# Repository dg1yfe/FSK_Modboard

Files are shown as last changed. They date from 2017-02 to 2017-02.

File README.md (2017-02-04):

# FSK_Modboard
A little amplifier board for Demodulator &amp; Modulator access in Motorola MC micro transceivers 

The board provides uses a dual OP-Amp to do the following:

1) Transmit Path
   - Provide an external input for direct (wide-band) modulator access
   - Amplify the signal supplied via the external input by a factor of 2.7
   - Add microphone audio signal and (amplified) external signal and route the mix to the modulator
     (be sure to disconnect or mute your microphone when using the external input)
 
2) Receive Path
   - Pick-up the demodulated signal right after the demodulator and amplify it by 10
   - Provide the amplified signal (amplitude about ~500 mV) at an external output

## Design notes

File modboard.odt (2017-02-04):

R1 - 47

R2 - 22k

R3 - 220k

R4 - 22k

R5 - 220k

R6 - 220k

R7 - 82k

C1 - 47n

C2 – 4u7

C3 - 4u7

C4 - 100p

C5 - 4u7

C6 - 47n

X1 - RX Signal vom Demodulator (z.B. Demod-IC / Pin 5)

X2 - FSK RX Signal zum Modem, DSUB Pin 7 (z.B. D652 Kathode)

X2A – mit Koppelkondensator

X2B – ohne Koppelkondensator

X3 - FSK TX Signal vom Modem, DSUB Pin 9 (z.B. D651 Kathode)

X4 - NF Signal vom Mikrofon (z.B. U601 / Pin 4)

X5 - Kombiniertes TX Signal zum Modulator (L602)

X6 - 9,6 V (z.B. U801 / Pin 11)

X7 - 4,8 V (z.B. U601 / Pin 9 )

X8 - GND / Masse (z.B. U601 / Pin 7)

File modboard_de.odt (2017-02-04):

R1 – 47 Ohm

R2 – 22 kOhm

R3 – 220 kOhm

R4 – 22 kOhm

R5 – 220 kOhm

R6 – 220 kOhm

R7 – 82 kOhm

C1 – 47 nF

C2 – 4,7 µF

C3 – 4,7 µF

C4 – 100 pF

C5 – 4,7 µF

C6 – 47nF

Kontakt Beschreibung Anschlusspunkt

X1 RX Signal vom Demodulator (Demod-IC / Pin 5)

X2 FSK RX Signal zum Modem, DSUB Pin 7 (z.B. D652 Kathode)

X2A – mit Koppelkondensator

X2B – ohne Koppelkondensator

X3 Kombiniertes TX Signal zum Modulator (L602)

X4 NF Signal vom Mikrofon (z.B. U601 / Pin 4)

X5 FSK TX Signal vom Modem, DSUB Pin 9 (z.B. D651 Kathode)

X6 9,6 V (z.B. U801 / Pin 11)

X7 4,8 V (z.B. U601 / Pin 9 )

X8 GND / Masse (z.B. U601 / Pin 7)

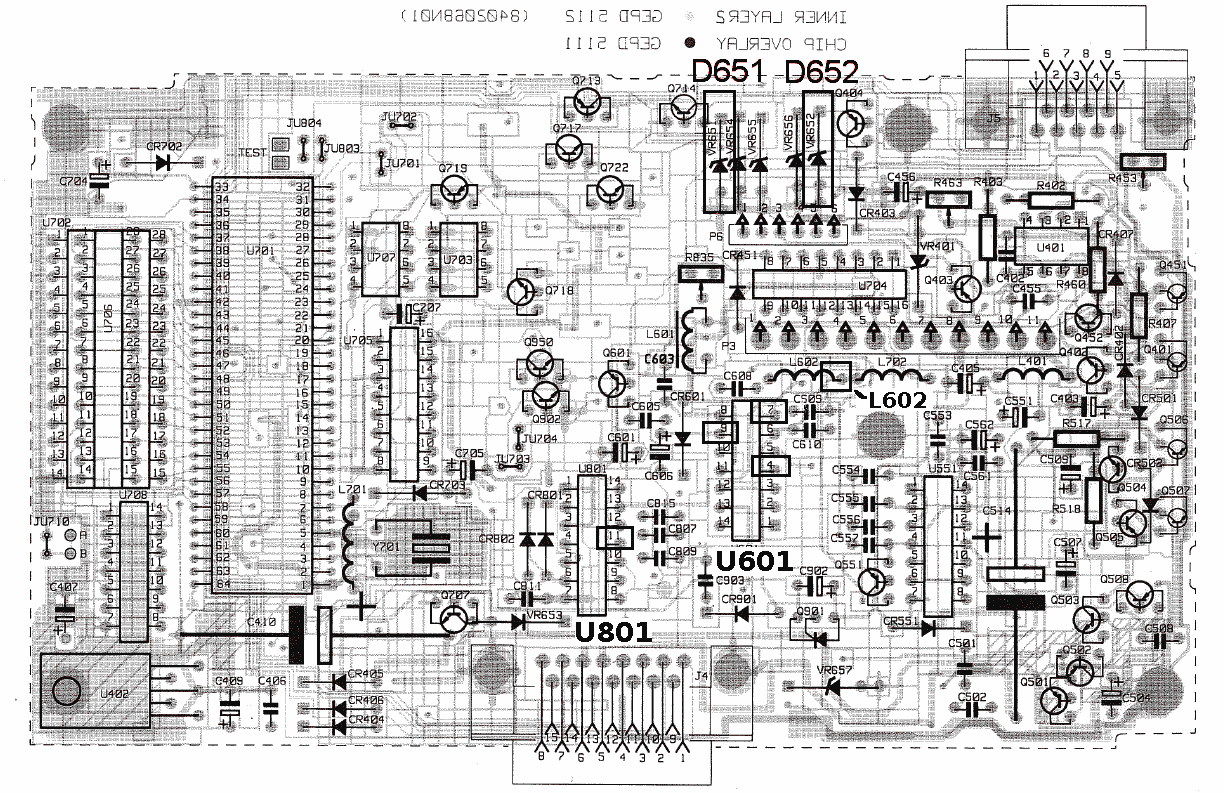
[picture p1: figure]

Command Board

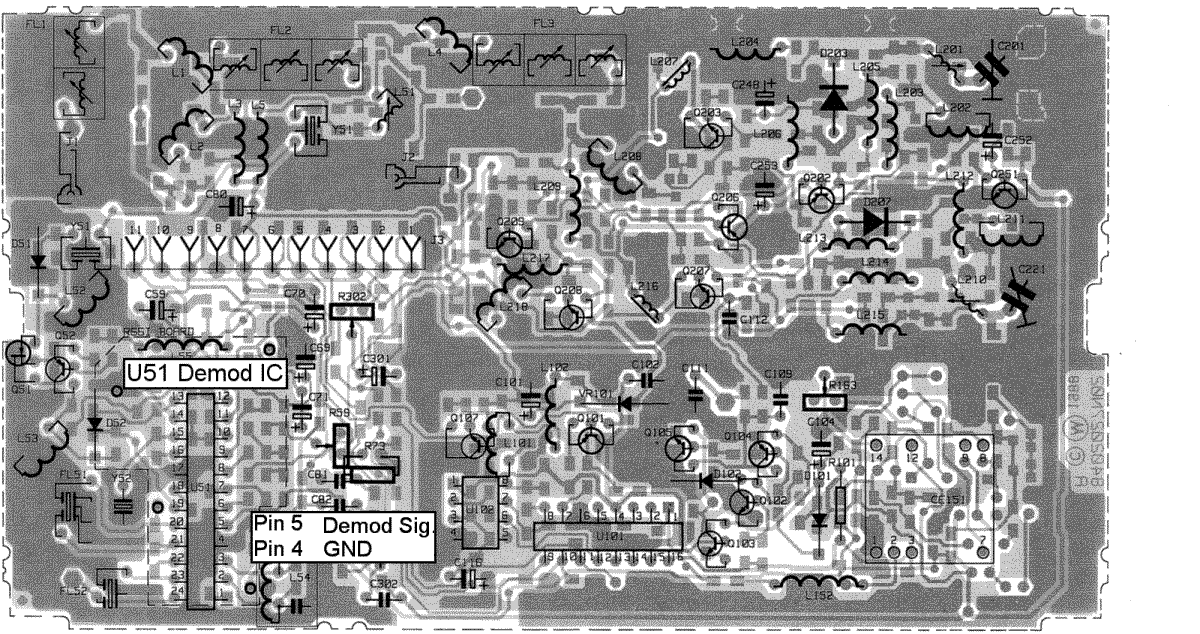
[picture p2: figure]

RF Board

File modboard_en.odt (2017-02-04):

R1 – 47 Ohm

R2 – 22 k

R3 – 220 k

R4 – 22 k

R5 – 220 k

R6 – 220 k

R7 – 82 k

C1 – 47 n

C2 – 4u7

C3 – 4u7

C4 – 100 p

C5 – 4u7

C6 – 47 n

Soldering Point Description Connection in TRX

X1 RX signal from discriminator Demod-IC / Pin 5

X2 FSK RX out to Modem, DSUB Pin 7 e.g. D652 cathode

X2A – AC-coupled

X2B – DC-coupled

X3 Combined signal / to modulator L602

X4 NF audio from microphone U601 / Pin 4

X5 FSK TX sig. from Modem, DSUB Pin 9 e.g. D651 cathode

X6 9.6 V e.g. U801 / Pin 11

X7 4.8 V e.g. U601 / Pin 9

X8 GND e.g. U601 / Pin 7


Command Board


RF Board

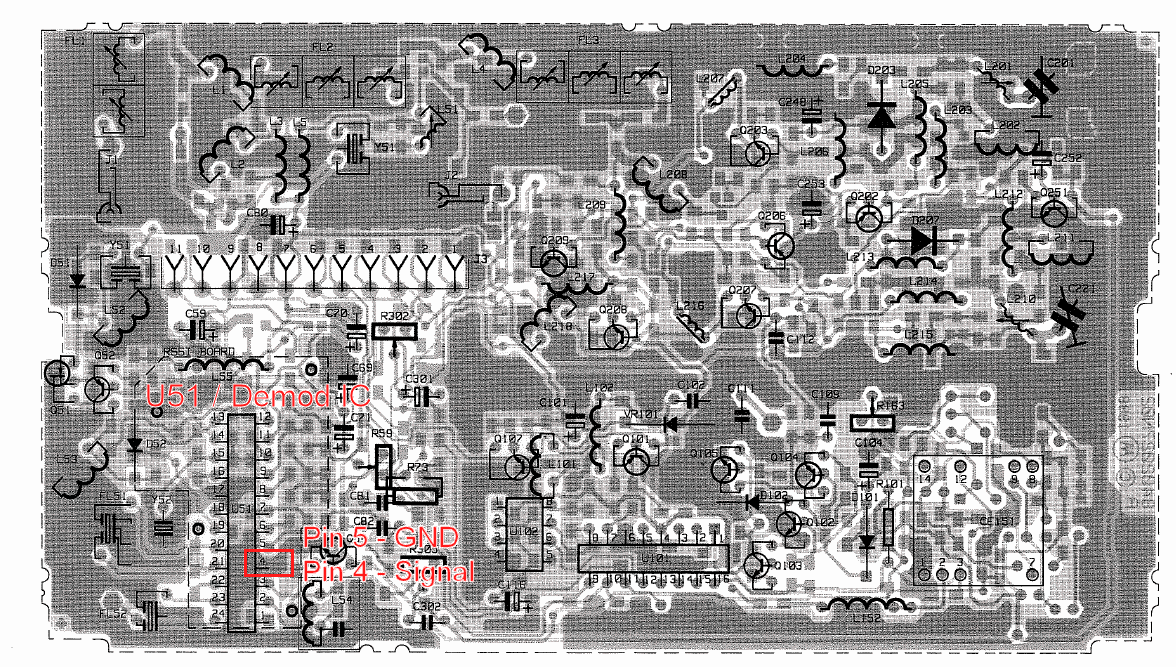
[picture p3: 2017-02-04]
RF_Board.png

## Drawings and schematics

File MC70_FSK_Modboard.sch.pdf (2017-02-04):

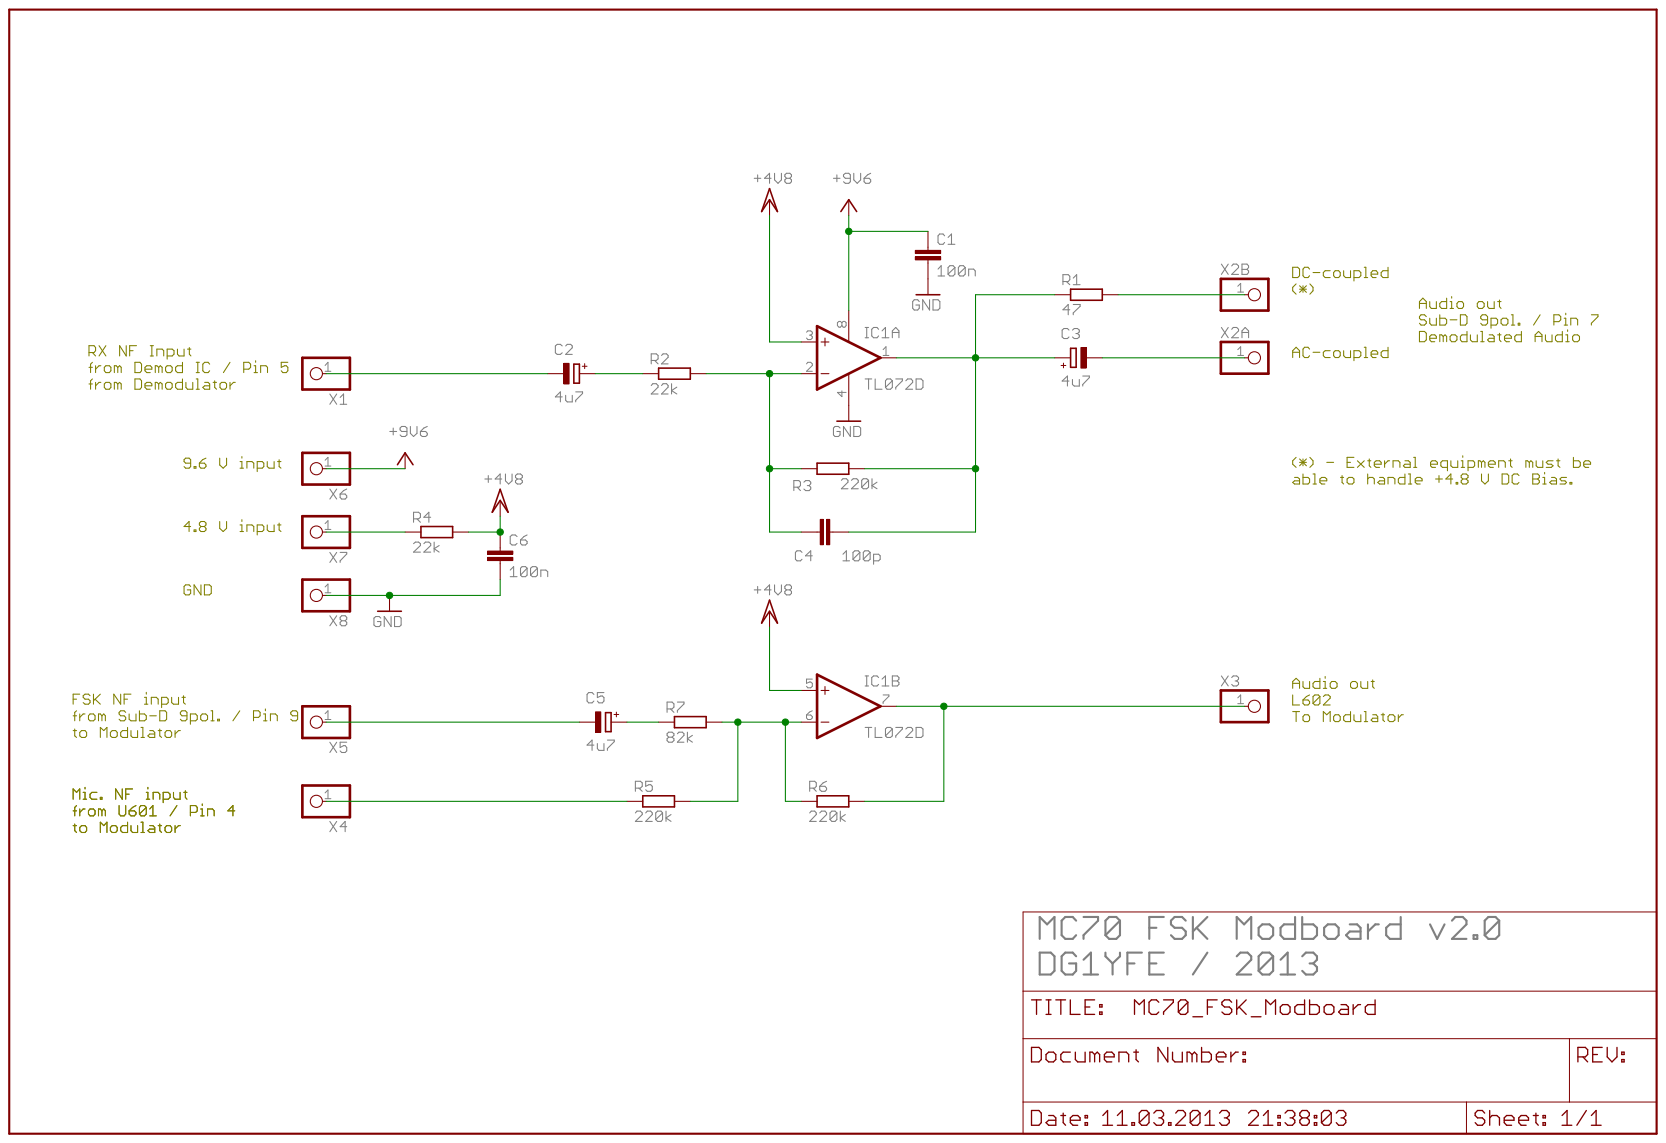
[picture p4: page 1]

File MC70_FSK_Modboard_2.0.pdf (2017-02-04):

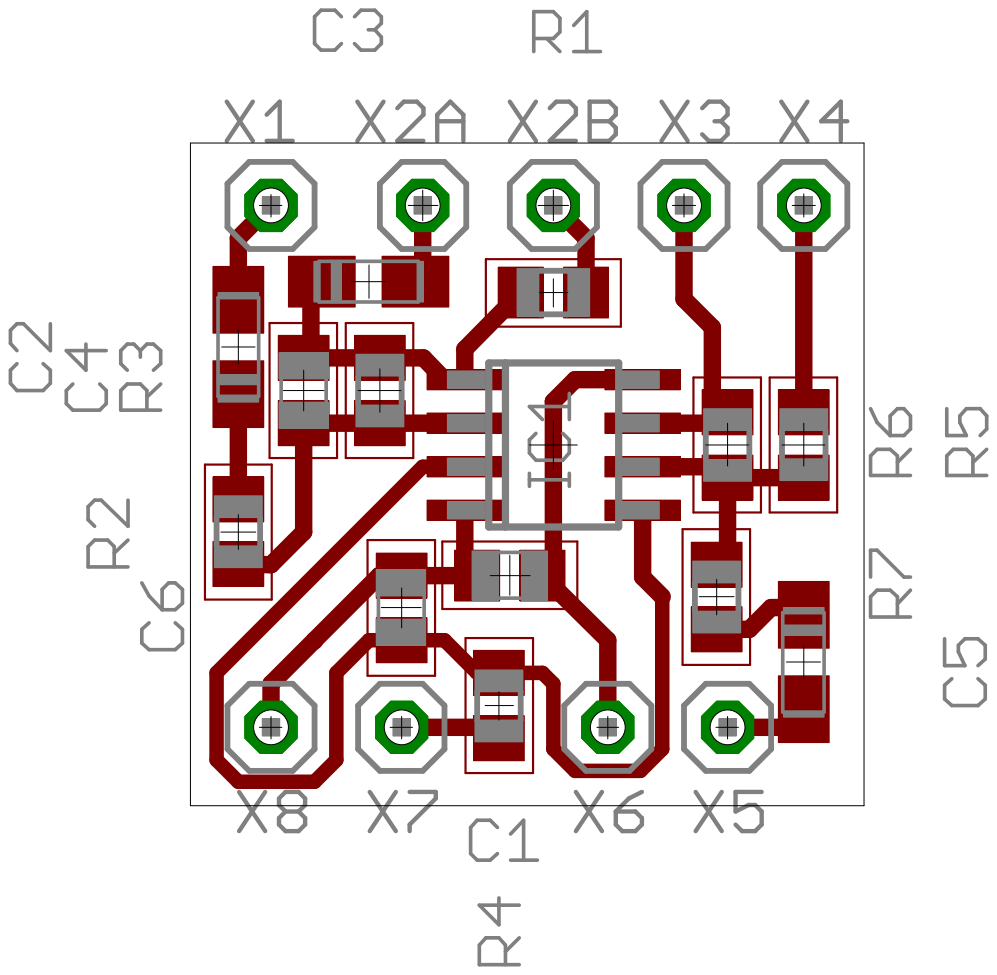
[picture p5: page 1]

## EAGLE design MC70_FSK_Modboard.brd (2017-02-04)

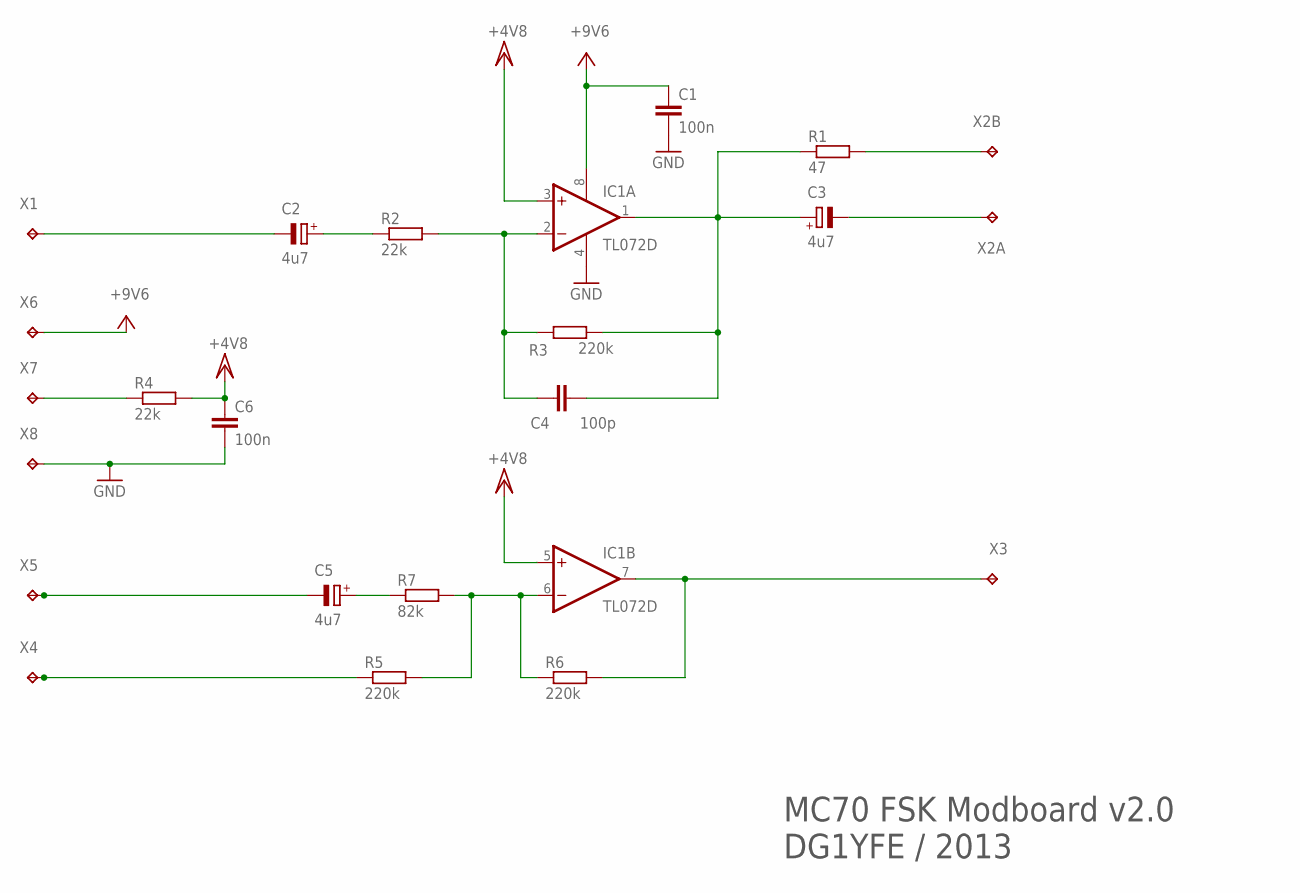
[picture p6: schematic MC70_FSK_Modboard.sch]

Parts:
C1, C6: 100n; C0805
C2, C3, C5: 4u7; A/3216-18R
C4: 100p; C0805
IC1: TL072D; SO08
R1: 47; R0805
R2, R4: 22k; R0805
R3, R5, R6: 220k; R0805
R7: 82k; R0805
X1, X2A, X2B, X3, X4, X5, X6, X7, X8: TPTP15R; TP15R

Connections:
GND: C1.2, C6.2, IC1.4 (V-), X8.TP
unnamed: IC1.7 (OUT), R6.2, X3.TP
unnamed: R5.1, X4.TP
unnamed: IC1.6 (-IN), R5.2, R6.1, R7.2
unnamed: C5.+, R7.1
unnamed: C5.-, X5.TP
unnamed: C2.-, X1.TP
unnamed: C2.+, R2.1
unnamed: R4.1, X7.TP
unnamed: C4.2, IC1.2 (-IN), R2.2, R3.1
unnamed: C3.+, C4.1, IC1.1 (OUT), R1.1, R3.2
unnamed: C3.-, X2A.TP
unnamed: R1.2, X2B.TP
VCC: C1.1, IC1.8 (V+), X6.TP
VCC/2: C6.1, IC1.3 (+IN), IC1.5 (+IN), R4.2

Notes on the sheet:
MC70 FSK Modboard v2.0 DG1YFE / 2013

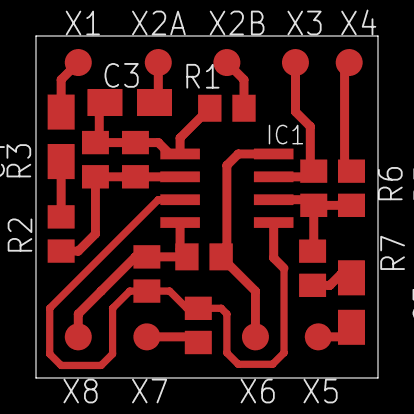
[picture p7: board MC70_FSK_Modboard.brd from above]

Board: 2 copper layers, 19.0 x 19.0 mm, 23 parts (0 on the bottom side), 15 nets.

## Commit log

2013-03-12 Modboard 2.0
    [MC70_FSK_Modboard.brd, MC70_FSK_Modboard.sch]
2017-02-04 Doku auf Stand gebracht und ins Repo gepackt
    [MC70_FSK_Modboard.brd]
